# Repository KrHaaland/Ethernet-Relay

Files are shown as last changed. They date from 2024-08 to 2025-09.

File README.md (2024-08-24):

# Ethernet-Relay
Relay module using ethernet and MQTT

Put togethet with parts i had laying around.

Its based on a Atmega328p using minicore Arduino bootloader, running at 8Mhz at 3.3 volts.

Ethernet is a W5500-module brought from aliexpress, a 24LC512 for storing the web-interface, FT232 for communicating via usb and updating FW.

The mqtt topic postfix is "/relay1/set" and "/relay2/set" for turing the relays on or off, and "/relay1" or "/relay2" for getting the current status of the relays, the staus will be published according to update time set in the web-interface.

PCB is drawn in Kicad and the casing is draw using solidworks and printed on a Prusa mini+ 3D-Printer.
The print has inserts melted in place to have threads, used for fasten pcb and the back lid.

Some Instructions, the external EEPROM is written by a seperate program, since the controller is to small to contain the web page while running the primary program. When the EEPROM is written the primary program is uploaded and are using the data on the EEPROM to send the web page to a web-client request.

The FT232 is default set to 100mA, this might not be a problem if the device is powered by a charger, but beeing powered by the USB of a computer 100mA is not enough to power the ethernet or relays, this is solved using [FT_PROG](https://ftdichip.com/utilities/) to configure the FT232 to be able to draw up to 500mA.

</br><br></br><br></br><br>
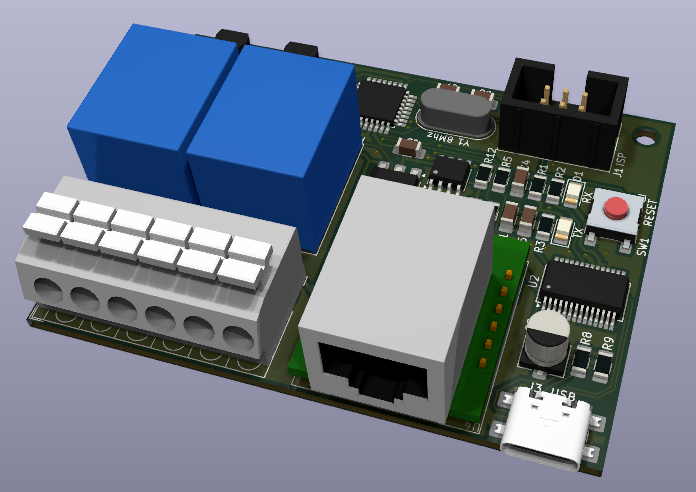
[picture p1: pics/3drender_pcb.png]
3D Render of PCB


</br><br></br><br></br><br>
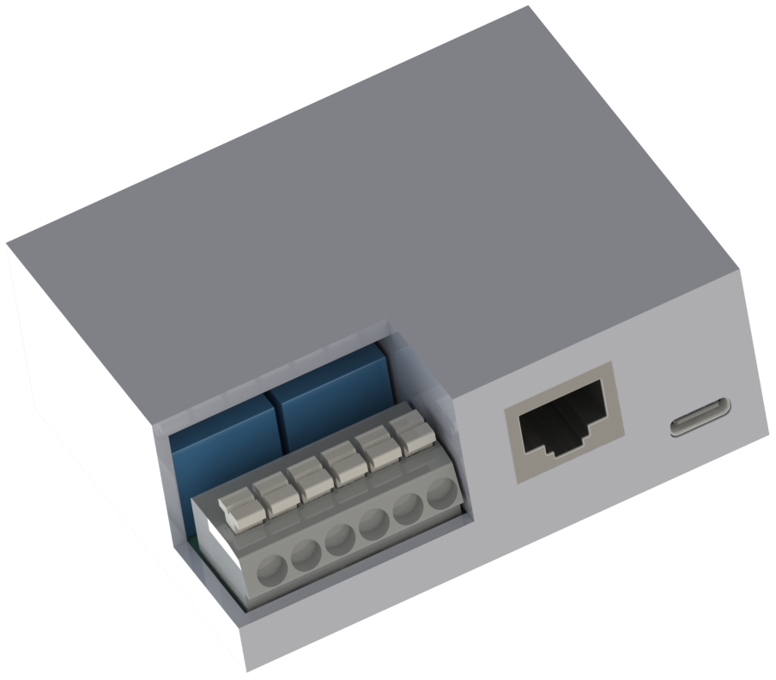
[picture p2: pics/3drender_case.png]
3D Render of case


</br><br></br><br></br><br>
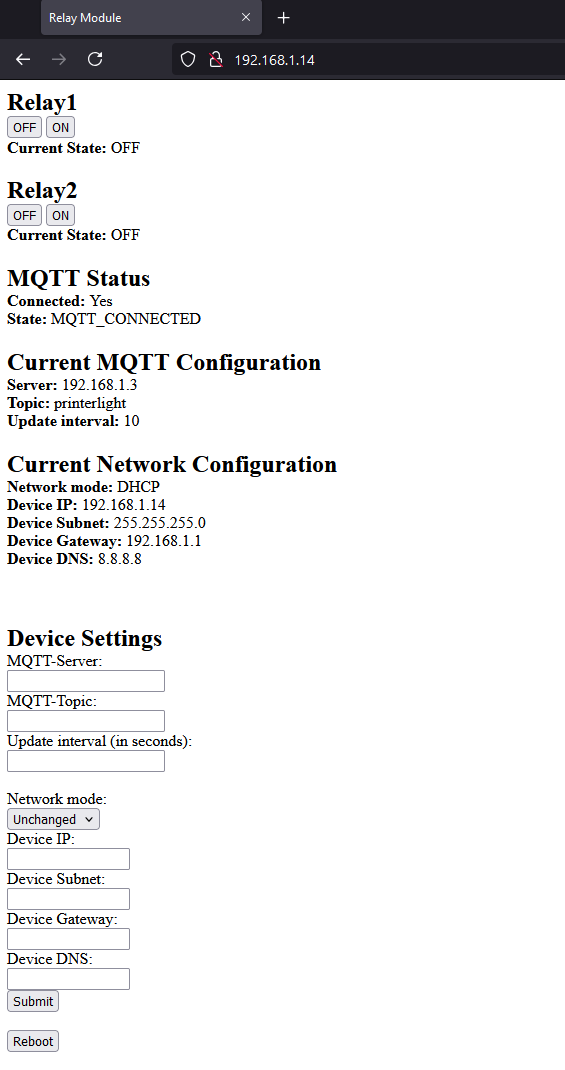
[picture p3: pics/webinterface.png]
Web Interface


</br><br></br><br></br><br>
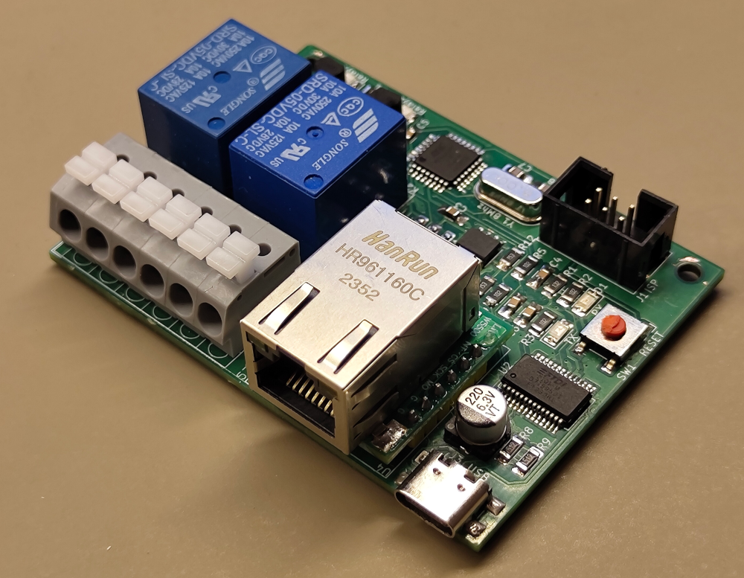
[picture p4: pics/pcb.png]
PCB


</br><br></br><br></br><br>
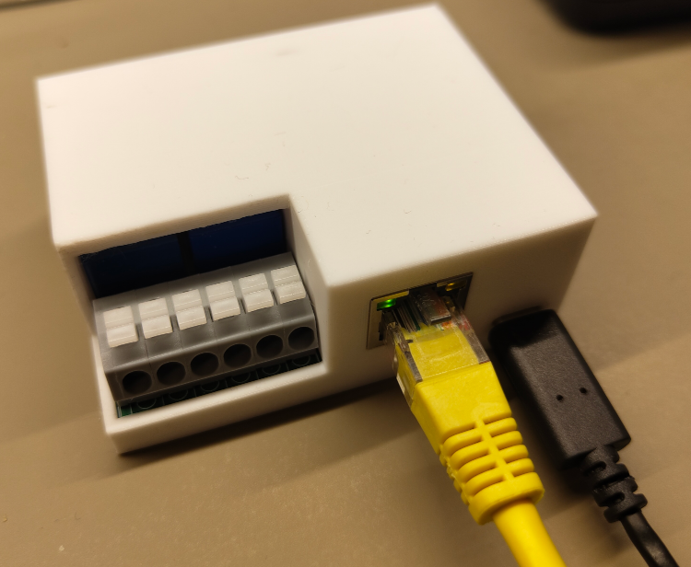
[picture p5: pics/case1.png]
Case 1


</br><br></br><br></br><br>
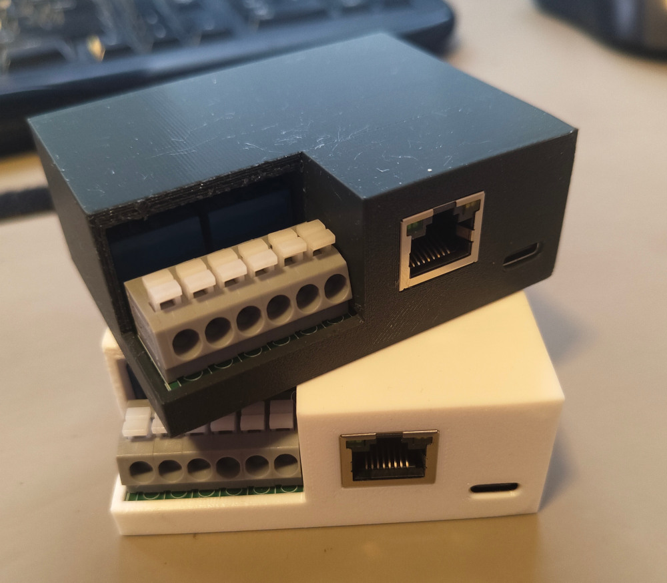
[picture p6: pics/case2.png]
Case 2


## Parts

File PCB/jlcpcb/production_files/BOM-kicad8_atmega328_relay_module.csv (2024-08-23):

Comment | Designator | Footprint | LCSC
1µF | C5 | C_1206_3216Metric_Pad1.33x1.80mm_HandSolder
16Mhz | Y1 | Crystal_HC49-4H_Vertical
SW_Omron_B3FS | SW1 | SW_SPST_Omron_B3FS-100xP
1K | R4 | R_1206_3216Metric_Pad1.30x1.75mm_HandSolder
SRD-05VDC-SL-C | K1 | Relay_SPDT_SANYOU_SRD_Series_Form_C
100µF | C2 | CP_Elec_5x5.8
1K | R1 | R_1206_3216Metric_Pad1.30x1.75mm_HandSolder
20pF | C8 | C_1206_3216Metric_Pad1.33x1.80mm_HandSolder
AVR-ISP-6 | J1 | IDC-Header_2x03_P2.54mm_Vertical
ATmega328P-A | U1 | TQFP-32_7x7mm_P0.8mm
5.1K | R9 | R_1206_3216Metric_Pad1.30x1.75mm_HandSolder
1K | R5 | R_1206_3216Metric_Pad1.30x1.75mm_HandSolder
1N4007 | D3 | D_DO-41_SOD81_P7.62mm_Horizontal
BC546 | Q2 | TO-92_Inline
1µF | C1 | C_1206_3216Metric_Pad1.33x1.80mm_HandSolder
USB_C | J3 | USB_C_Receptacle_GCT_USB4110
100nF | C4 | C_1206_3216Metric_Pad1.33x1.80mm_HandSolder
1K | R2 | R_1206_3216Metric_Pad1.30x1.75mm_HandSolder
1µF | C6 | C_1206_3216Metric_Pad1.33x1.80mm_HandSolder
AMS1117-3.3 | U3 | SOT-223-3_TabPin2
20pF | C7 | C_1206_3216Metric_Pad1.33x1.80mm_HandSolder
5.1K | R8 | R_1206_3216Metric_Pad1.30x1.75mm_HandSolder
RX-RED | D1 | LED_1206_3216Metric_Pad1.42x1.75mm_HandSolder
1K | R7 | R_1206_3216Metric_Pad1.30x1.75mm_HandSolder
1N4007 | D4 | D_DO-41_SOD81_P7.62mm_Horizontal
TX-GREEN | D2 | LED_1206_3216Metric_Pad1.42x1.75mm_HandSolder
SRD-05VDC-SL-C | K2 | Relay_SPDT_SANYOU_SRD_Series_Form_C
~ | U4 | W5500Mini
BC546 | Q1 | TO-92_Inline
1µF | C3 | C_1206_3216Metric_Pad1.33x1.80mm_HandSolder
Screw_Terminal_01x06 | J4 | TerminalBlock_WAGO_804-106_1x06_P5.00mm_45Degree
1K | R6 | R_1206_3216Metric_Pad1.30x1.75mm_HandSolder
1K | R3 | R_1206_3216Metric_Pad1.30x1.75mm_HandSolder
FT232RL | U2 | SSOP-28_5.3x10.2mm_P0.65mm
10K | R13 | R_1206_3216Metric_Pad1.30x1.75mm_HandSolder
1K | R10 | R_1206_3216Metric_Pad1.30x1.75mm_HandSolder
24LC512 | U5 | SOIC-8_3.9x4.9mm_P1.27mm
Relay1 | D5 | LED_1206_3216Metric_Pad1.42x1.75mm_HandSolder
10K | R12 | R_1206_3216Metric_Pad1.30x1.75mm_HandSolder
Relay2 | D6 | LED_1206_3216Metric_Pad1.42x1.75mm_HandSolder
1K | R11 | R_1206_3216Metric_Pad1.30x1.75mm_HandSolder

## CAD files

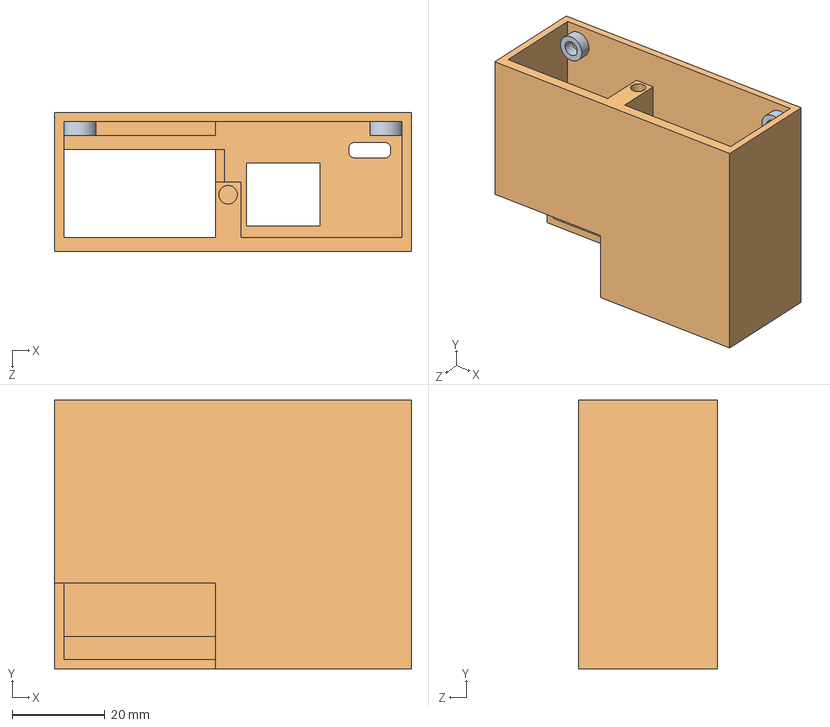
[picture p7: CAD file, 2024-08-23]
3d-files/casing.STEP
77.0 x 58.0 x 30.0 mm

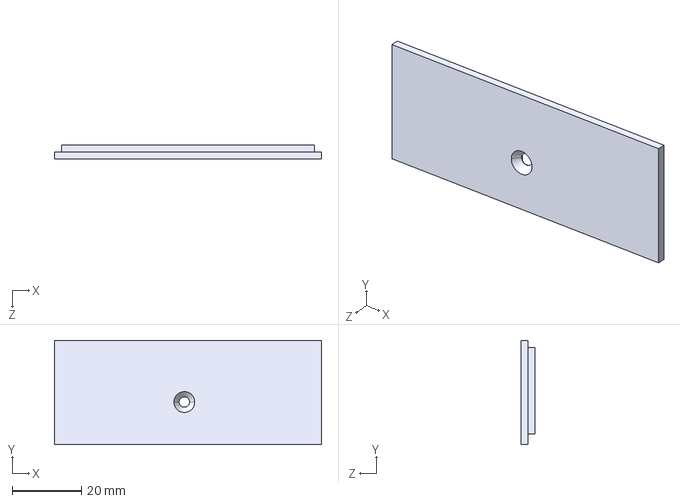
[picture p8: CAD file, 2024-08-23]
3d-files/lid.STEP
77.0 x 30.0 x 4.00 mm

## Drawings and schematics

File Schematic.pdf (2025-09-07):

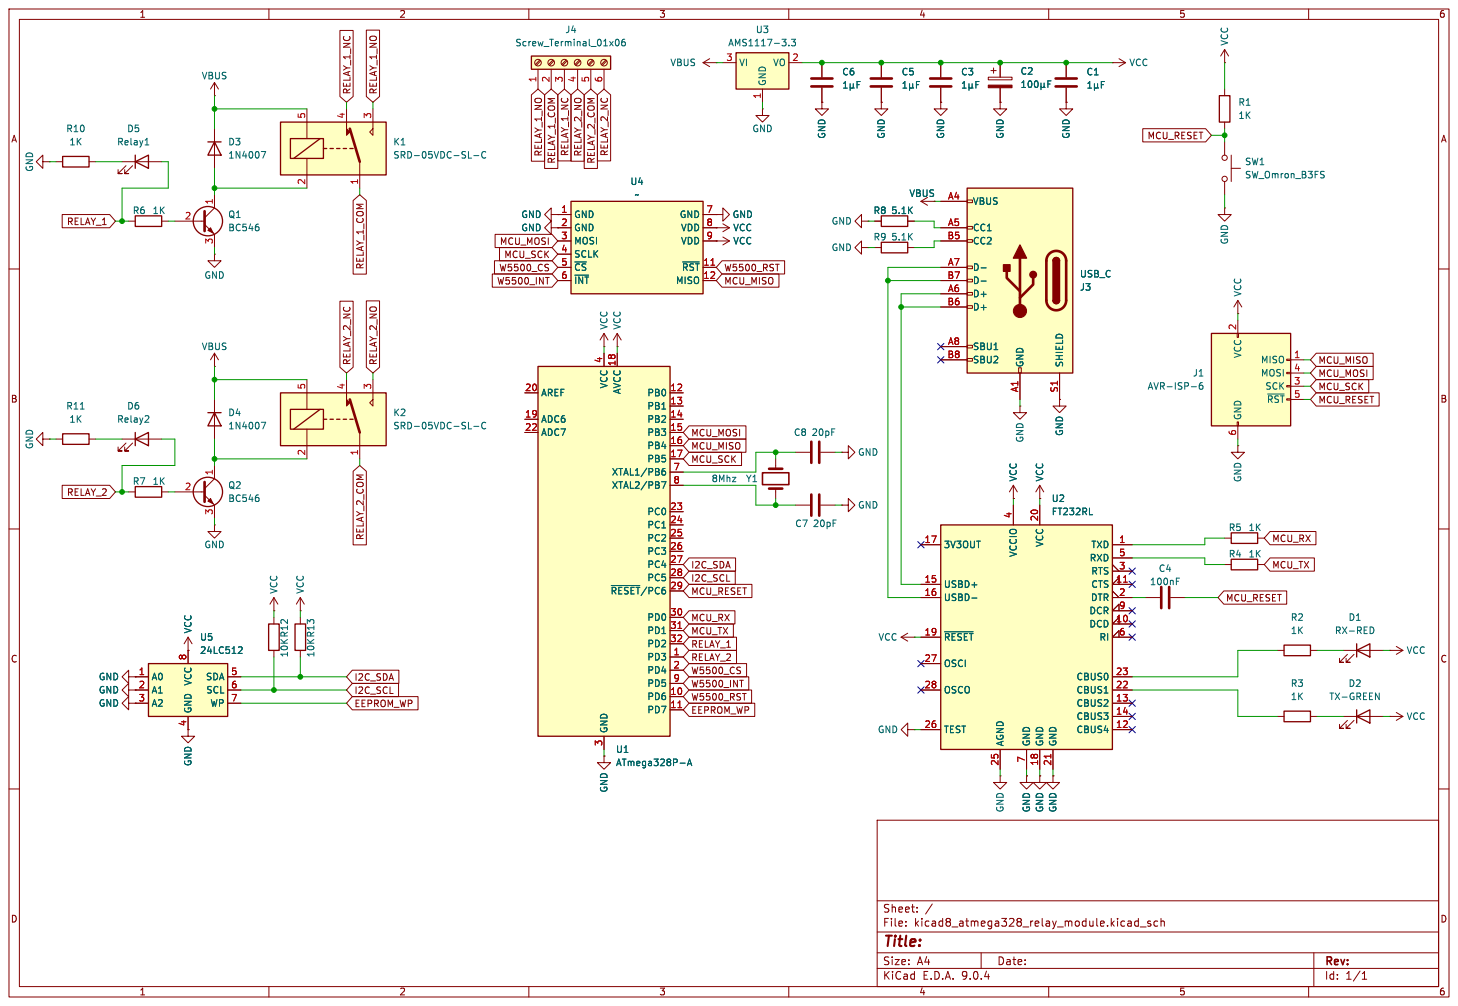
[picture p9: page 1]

7 VCC 20 GND 18 GND 21 TXD 1 RXD 5 RTS 3 CTS 11 DTR 2 DCR 9 DCD 10 RI 6 CBUS0 23 CBUS1 22 CBUS2 13 CBUS3 14 CBUS4 12 U2 FT232RL GND

3 AVCC 18 PB0 12 PB1 13 PB2 14 PB3 15 PB4 16 PB5 17 XTAL1/PB6 7 XTAL2/PB7 8 PC0 23 PC1 24 PC2 25 PC3 26 PC4 27 PC5 28 ~{RESET}/PC629 PD0 30 PD1 31 PD2 32 PD3 1 PD4 2 PD5 9 PD6 10 PD7 11 U1ATmega328P-A SHIELD S1 GND A1 VBUS A4 CC1 A5 CC2 B5 D- A7 D- B7 D+ A6 D+ B6 SBU1 A8 SBU2 B8

6 MISO 1 MOSI 4 SCK 3 ~{RST}5

3 K2SRD-05VDC-SL-C VCC GND VCC R12 10K GND VCC

7 VCC 20 GND 18 GND 21 TXD 1 RXD 5 RTS 3 CTS 11 DTR 2 DCR 9 DCD 10 RI 6 CBUS0 23 CBUS1 22 CBUS2 13 CBUS3 14 CBUS4 12 GND GND GND

4 SDA 5 SCL 6 WP 7 GND GND VCC

Id: 1/1 Title: File: kicad8_atmega328_relay_module.kicad_sch Sheet: /

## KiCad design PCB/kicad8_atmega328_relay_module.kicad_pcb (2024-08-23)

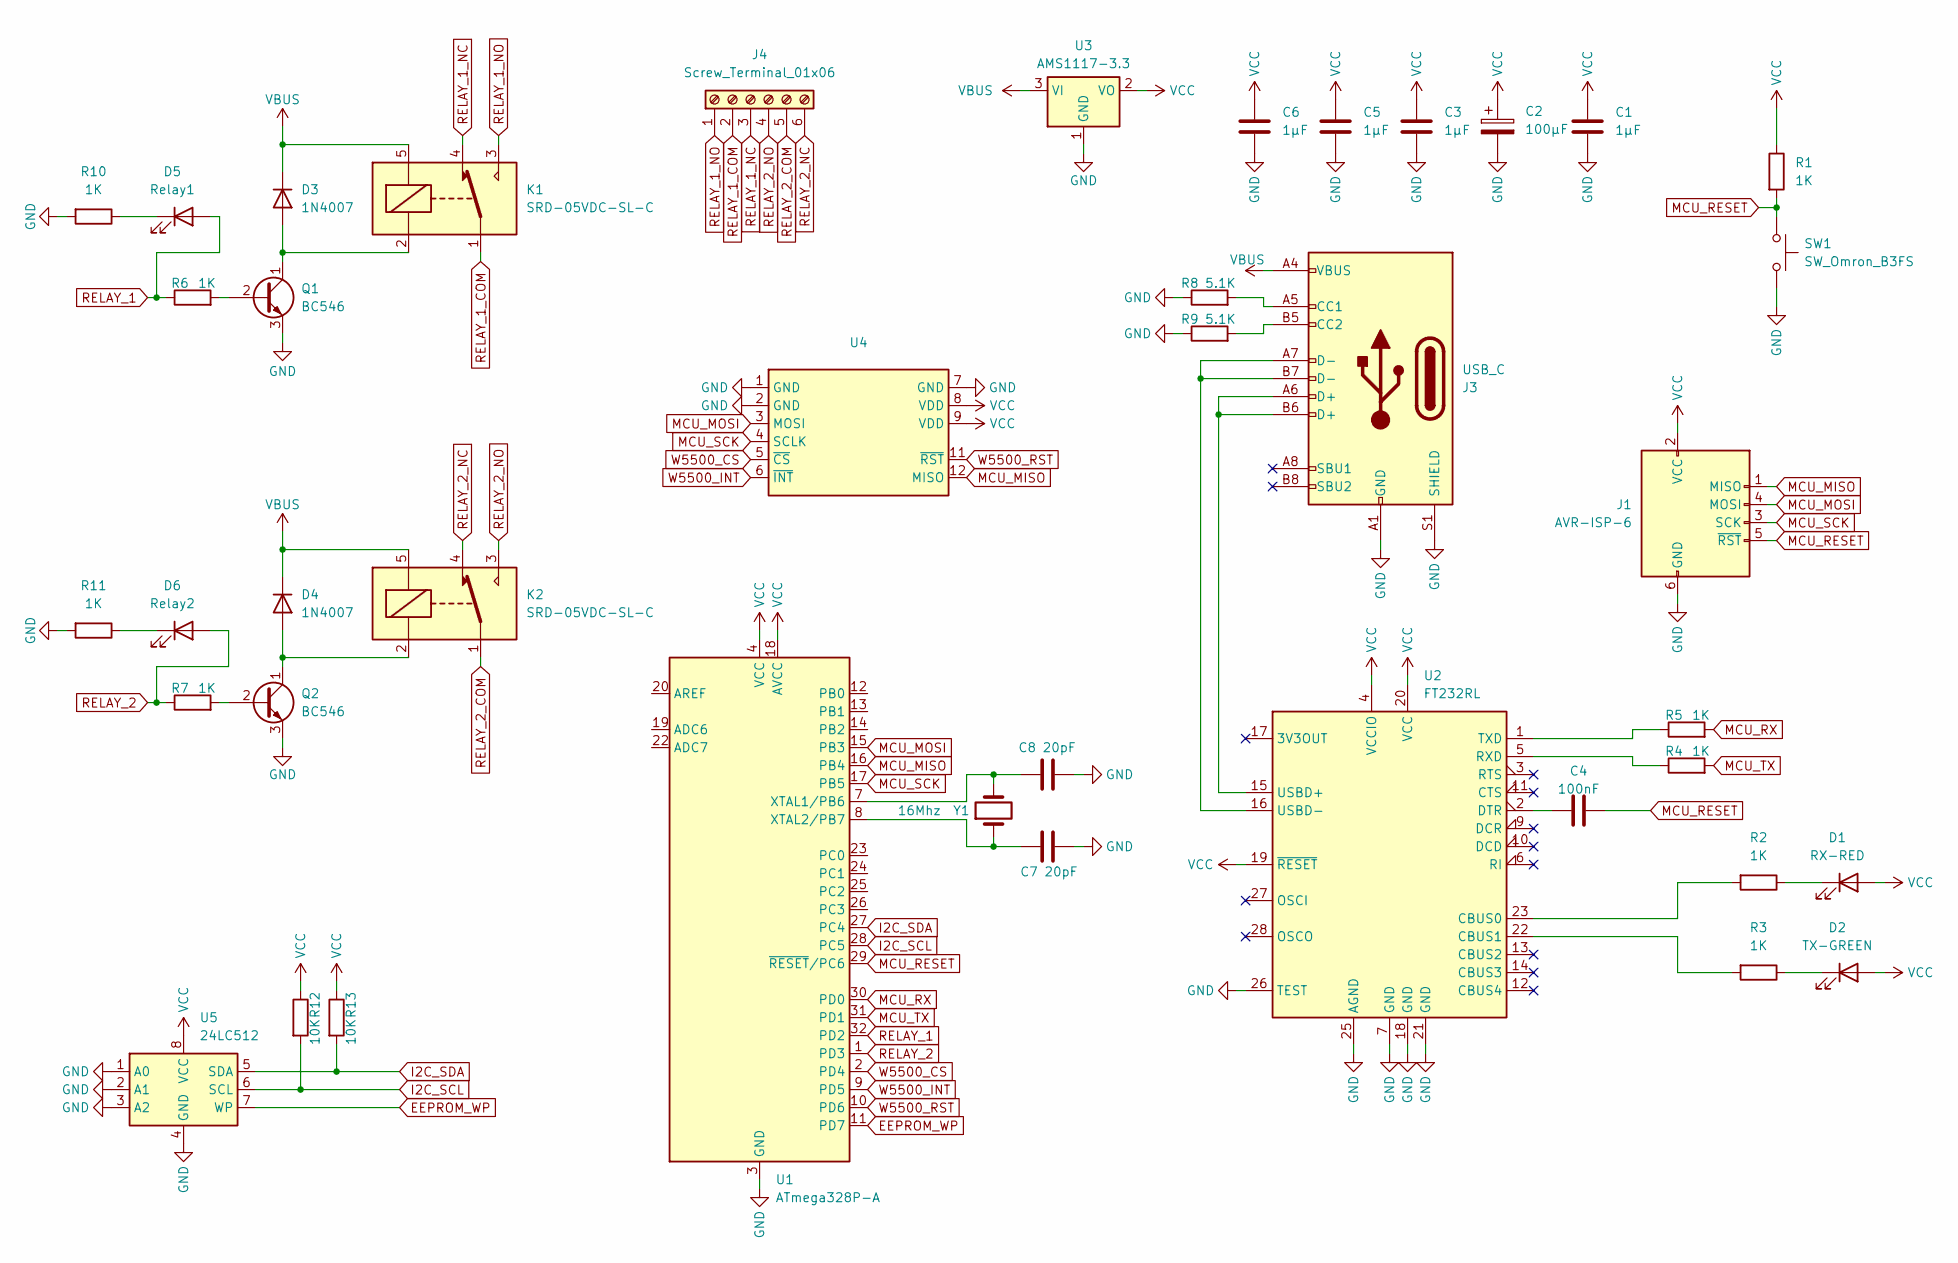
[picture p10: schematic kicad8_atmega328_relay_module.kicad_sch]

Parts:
C1, C3, C5, C6: 1µF; C_1206_3216Metric_Pad1.33x1.80mm_HandSolder
C2: 100µF; CP_Elec_5x5.8
C4: 100nF; C_1206_3216Metric_Pad1.33x1.80mm_HandSolder
C7, C8: 20pF; C_1206_3216Metric_Pad1.33x1.80mm_HandSolder
D1: RX-RED; LED_1206_3216Metric_Pad1.42x1.75mm_HandSolder
D2: TX-GREEN; LED_1206_3216Metric_Pad1.42x1.75mm_HandSolder
D3, D4: 1N4007; D_DO-41_SOD81_P7.62mm_Horizontal
D5: Relay1; LED_1206_3216Metric_Pad1.42x1.75mm_HandSolder
D6: Relay2; LED_1206_3216Metric_Pad1.42x1.75mm_HandSolder
J1: AVR-ISP-6; IDC-Header_2x03_P2.54mm_Vertical
J3: USB_C; USB_C_Receptacle_GCT_USB4110
J4: Screw_Terminal_01x06; TerminalBlock_WAGO_804-106_1x06_P5.00mm_45Degree
K1, K2: SRD-05VDC-SL-C; Relay_SPDT_SANYOU_SRD_Series_Form_C
Q1, Q2: BC546; TO-92_Inline
R1, R2, R3, R4, R5, R6, R7, R10, R11: 1K; R_1206_3216Metric_Pad1.30x1.75mm_HandSolder
R8, R9: 5.1K; R_1206_3216Metric_Pad1.30x1.75mm_HandSolder
R12, R13: 10K; R_1206_3216Metric_Pad1.30x1.75mm_HandSolder
SW1: SW_Omron_B3FS; SW_SPST_Omron_B3FS-100xP
U1: ATmega328P-A; TQFP-32_7x7mm_P0.8mm
U2: FT232RL; SSOP-28_5.3x10.2mm_P0.65mm
U3: AMS1117-3.3; SOT-223-3_TabPin2
U4: W5500Mini
U5: 24LC512; SOIC-8_3.9x4.9mm_P1.27mm
Y1: 16Mhz; Crystal_HC49-4H_Vertical

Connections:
EEPROM_WP: U1.11 (PD7), U5.7 (WP)
GND: C1.2, C2.2, C3.2, C5.2, C6.2, C7.2, C8.2, J1.6 (GND), J3.A1 (GND), J3.A12 (GND), J3.B1 (GND), J3.B12 (GND), J3.S1 (SHIELD), Q1.3 (E), Q2.3 (E), R8.1, R9.1, R10.2, R11.2, SW1.2, U1.3 (GND), U1.5 (GND), U1.21 (GND), U2.7 (GND), U2.18 (GND), U2.21 (GND), U2.25 (AGND), U2.26 (TEST), U3.1 (GND), U4.1 (GND), U4.2 (GND), U4.7 (GND), U5.1 (A0), U5.2 (A1), U5.3 (A2), U5.4 (GND)
I2C_SCL: R12.2, U1.28 (PC5), U5.6 (SCL)
I2C_SDA: R13.2, U1.27 (PC4), U5.5 (SDA)
MCU_MISO: J1.1 (MISO), U1.16 (PB4), U4.12 (MISO)
MCU_MOSI: J1.4 (MOSI), U1.15 (PB3), U4.3 (MOSI)
MCU_RESET: C4.1, J1.5 (~RST), R1.2, SW1.1, U1.29 (~RESET/PC6)
MCU_RX: R5.2, U1.30 (PD0)
MCU_SCK: J1.3 (SCK), U1.17 (PB5), U4.4 (SCLK)
MCU_TX: R4.2, U1.31 (PD1)
unnamed: D1.1 (K), R2.1
unnamed: D2.1 (K), R3.1
unnamed: D3.2 (A), K1.2, Q1.1 (C)
unnamed: D4.2 (A), K2.2, Q2.1 (C)
unnamed: D5.1 (K), R10.1
unnamed: D6.1 (K), R11.1
unnamed: J3.A5 (CC1), R8.2
unnamed: J3.B5 (CC2), R9.2
unnamed: Q1.2 (B), R6.2
unnamed: Q2.2 (B), R7.2
unnamed: C8.1, U1.7 (XTAL1/PB6), Y1.2
unnamed: C7.1, U1.8 (XTAL2/PB7), Y1.1
unnamed: R2.2, U2.23 (CBUS0)
unnamed: R3.2, U2.22 (CBUS1)
unnamed: C4.2, U2.2 (DTR)
unnamed: R4.1, U2.5 (RXD)
unnamed: R5.1, U2.1 (TXD)
RELAY_1: D5.2 (A), R6.1, U1.32 (PD2)
RELAY_1_COM: J4.2, K1.1
RELAY_1_NC: J4.3, K1.4
RELAY_1_NO: J4.1, K1.3
RELAY_2: D6.2 (A), R7.1, U1.1 (PD3)
RELAY_2_COM: J4.5, K2.1
RELAY_2_NC: J4.6, K2.4
RELAY_2_NO: J4.4, K2.3
USB_D+: J3.A6 (D+), J3.B6 (D+), U2.15 (USBD+)
USB_D-: J3.A7 (D-), J3.B7 (D-), U2.16 (USBD-)
VBUS: D3.1 (K), D4.1 (K), J3.A4 (VBUS), J3.A9 (VBUS), J3.B4 (VBUS), J3.B9 (VBUS), K1.5, K2.5, U3.3 (VI)
VCC: C1.1, C2.1, C3.1, C5.1, C6.1, D1.2 (A), D2.2 (A), J1.2 (VCC), R1.1, R12.1, R13.1, U1.4 (VCC), U1.6 (VCC), U1.18 (AVCC), U2.4 (VCCIO), U2.19 (~RESET), U2.20 (VCC), U3.2 (VO), U4.8 (VDD), U4.9 (VDD), U5.8 (VCC)
W5500_CS: U1.2 (PD4), U4.5 (~CS)
W5500_INT: U1.9 (PD5), U4.6 (~INT)
W5500_RST: U1.10 (PD6), U4.11 (~RST)

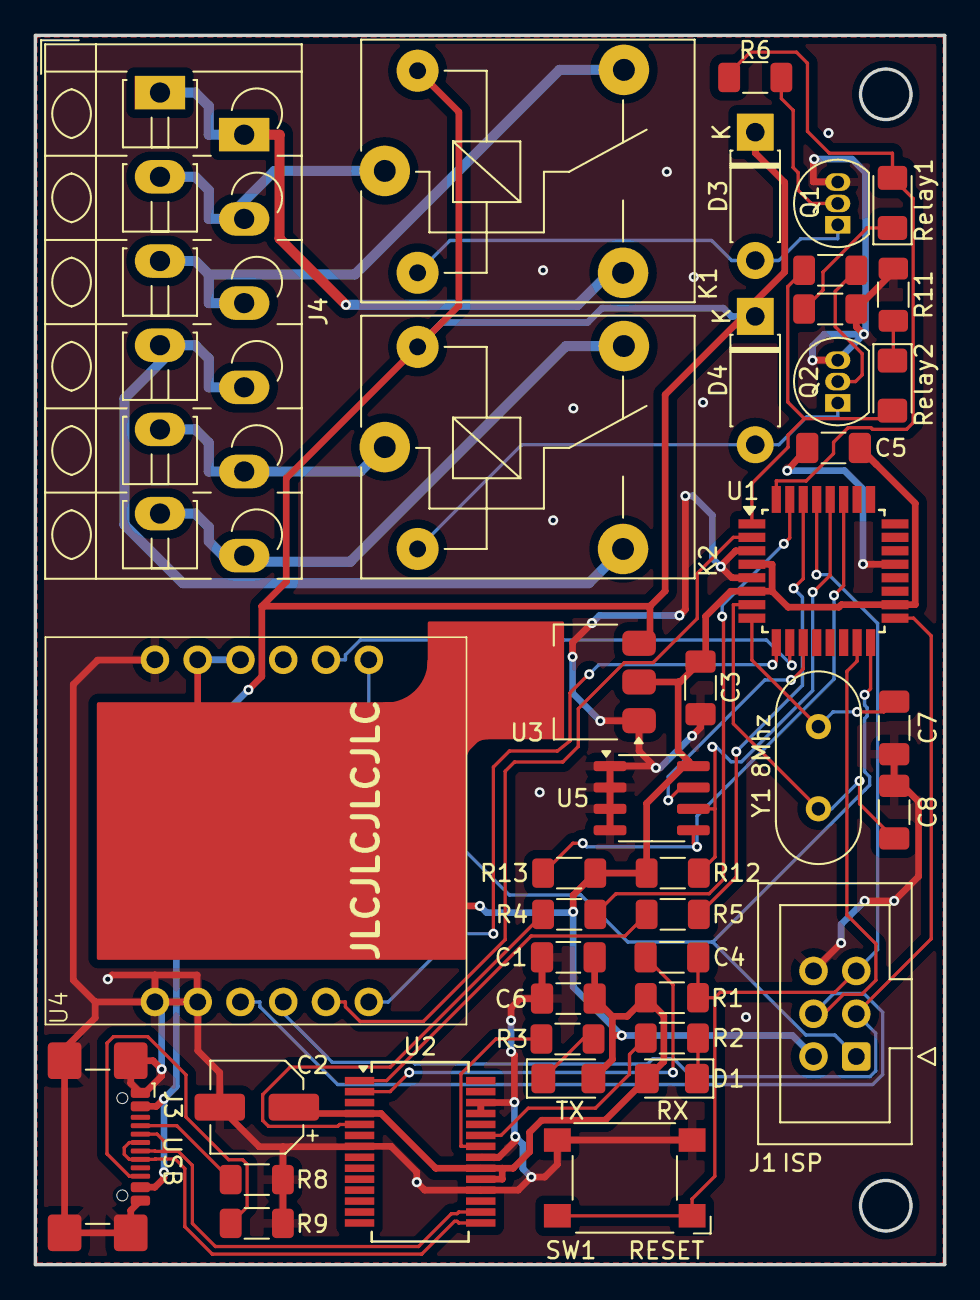
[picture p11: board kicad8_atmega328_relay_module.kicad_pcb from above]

Board: 2 copper layers, 54.0 x 73.0 mm, 41 parts (0 on the bottom side), 42 nets.

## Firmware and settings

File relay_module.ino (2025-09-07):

/**************************************
SOME NOTES

FT232:
Use FT_PROG to set bus power to 500mA,
Otherwise it wont give enough power to
supply ethernet module and relays!



/*************************************/

#include <SPI.h>
#include <Wire.h>
#include <PubSubClient.h>
#include <EEPROM.h>
#include <Ethernet.h>
#include <avr/wdt.h>
#include <avr/io.h>

// MAC address for your Ethernet shield
// BE SURE TO ALSO CHANGE MQTT CLIENT ID and serial output !!
//byte mac[] = { 0x02, 0x79, 0xFB, 0x22, 0x8C, 0x10 };  // First produced module
byte mac[] = { 0x0E, 0x97, 0xBF, 0xCF, 0x2F, 0x95 };  // Second produced module
#define W5500_CS   PIN_PD4
#define W5500_RST  PIN_PD6

//relays
#define RELAY1PIN PIN_PD2
#define RELAY2PIN PIN_PD3

// Initialize the Ethernet server
EthernetServer server(80);

// MQTT Client
EthernetClient ethClient;
PubSubClient mqttClient(ethClient);

// i2c-frequency
const uint16_t i2cclockfrequency = 400000;
#define EEPROM_I2C_ADDRESS 0x50  // The I2C address for the 24C512 EEPROM

// Global variables
unsigned long previousMillismeasure = 0;
int lastStaterelay1 = LOW;    // Variable to store the last state of the input
int lastStaterelay2 = LOW;    // Variable to store the last state of the input

void(* reboot) (void) = 0; //declare reset function at address 0

void restartMicrocontroller() {
  wdt_enable(WDTO_1S);  // Enable Watchdog Timer with a timeout of 15ms
}

// Function to connect to MQTT server
void connectToMqtt() {
  mqttClient.loop();
  char mqttServer[64];
  retrieveFromEEPROM2(32, mqttServer, sizeof(mqttServer));
  Serial.print(F("mqtt: "));
  Serial.println(mqttServer);
  mqttClient.setServer(mqttServer, 1883);

  while (!mqttClient.connected()) {
    Serial.println(F("Connecting to MQTT..."));
    if (mqttClient.connect("0E97BFCF2F95")) {
      Serial.println(F("Connected to MQTT"));

      // Subscribe to topics
      char mqttTopic[64];
      retrieveFromEEPROM2(96, mqttTopic, sizeof(mqttTopic));
      char topic1[70];
      char topic2[70];
      strcpy(topic1, mqttTopic);
      strcat(topic1, "/relay1/set");
      strcpy(topic2, mqttTopic);
      strcat(topic2, "/relay2/set");
      mqttClient.subscribe(topic1);
      mqttClient.subscribe(topic2);

    } 
    else {
      Serial.print(F("Failed, rc="));
      Serial.println(mqttClient.state());
      delay(5000);
    }
  }
}

// MQTT message callback function
void callback(char* topic, byte* payload, unsigned int length) {
  payload[length] = '\0'; // Null-terminate the payload
  String message = String((char*)payload);

  Serial.print(F("Message arrived ["));
  Serial.print(topic);
  Serial.print(F("] "));
  Serial.println(message);

  // Check the topic and payload to control relays
  if (strstr(topic, "/relay1/set")) {
    if (message == "ON" || message == "1") {
      digitalWrite(RELAY1PIN, HIGH);
      Serial.println(F("Relay 1 turned ON"));
    } else if (message == "OFF" || message == "0") {
      digitalWrite(RELAY1PIN, LOW);
      Serial.println(F("Relay 1 turned OFF"));
    }
  } else if (strstr(topic, "/relay2/set")) {
    if (message == "ON" || message == "1") {
      digitalWrite(RELAY2PIN, HIGH);
      Serial.println(F("Relay 2 turned ON"));
    } else if (message == "OFF" || message == "0") {
      digitalWrite(RELAY2PIN, LOW);
      Serial.println(F("Relay 2 turned OFF"));
    }
  }
}

// Function to publish to a specific subtopic
void publishToSubtopic(char* baseTopic, const char* subtopic, const char* message) {
  char fullTopic[75]; // Ensure this buffer is large enough
  strcpy(fullTopic, baseTopic);
  strcat(fullTopic, subtopic); // Directly concatenate the subtopic
  mqttClient.publish(fullTopic, message);
}

void processClientRequest(EthernetClient& client) {
  //Serial.println(freeMemory());
String httpReq = "";
bool gotGet = false;
bool gotHost = false;
String currentLine = "";

while (client.connected()) {
    if (client.available()) {
        char c = client.read();
        currentLine += c;

        // Look for lines that starts with "GET" and "Host" 
        // and keep only them, this in order to save ram

        // Check for the end of the line
        if (c == '\n') {
            // Check if the line contains "GET"
            if (currentLine.startsWith(F("GET"))) {
                gotGet = true;
                httpReq += currentLine;
            }

            // Check if the line contains "Host"
            if (currentLine.startsWith(F("Host"))) {
                gotHost = true;
                httpReq += currentLine;
            }

            // Clear the current line
            currentLine = "";
        String hostValue;
        if (gotGet && gotHost) {
          Serial.println(httpReq);
          // Check for "Host: " header
          // This is used to know if it should redirect back to IP or mDNS-name
          int pos1 = httpReq.indexOf(F("Host: "));
          if (pos1 != -1) {
            int endOfLineIndex = httpReq.indexOf('\n', pos1);
            hostValue = httpReq.substring(pos1 + 6, endOfLineIndex); // +6 to skip past "Host: "
          }
          // Check for "GET: " header
          int pos = httpReq.indexOf(F("GET /?in1="));
          if (pos != -1) {
            pos += 10; // Skip past "GET /?input1="
            // Extract input1
            int nextAmp = httpReq.indexOf('&', pos);
            String input1 = httpReq.substring(pos, nextAmp);

            // Extract input2
            pos = httpReq.indexOf(F("in2="), nextAmp) + 4;
            nextAmp = httpReq.indexOf('&', pos);
            String input2 = httpReq.substring(pos, nextAmp);

            // Extract input3
            pos = httpReq.indexOf(F("in3="), nextAmp) + 4;
            int endPos = httpReq.indexOf('&', pos);
            String input3 = httpReq.substring(pos, endPos);

            // Extract DHCP-selection
            pos = httpReq.indexOf(F("net="), nextAmp) + 4;
            endPos = httpReq.indexOf('&', pos);
            String dhcpselect = httpReq.substring(pos, endPos);

            // Extract input4
            pos = httpReq.indexOf(F("in4="), nextAmp) + 4;
            endPos = httpReq.indexOf('&', pos);
            String input4 = httpReq.substring(pos, endPos);

            // Extract input5
            pos = httpReq.indexOf(F("in5="), nextAmp) + 4;
            endPos = httpReq.indexOf('&', pos);
            String input5 = httpReq.substring(pos, endPos);

            // Extract input6
            pos = httpReq.indexOf(F("in6="), nextAmp) + 4;
            endPos = httpReq.indexOf('&', pos);
            String input6 = httpReq.substring(pos, endPos);

            // Extract input7
            pos = httpReq.indexOf(F("in7="), nextAmp) + 4;
            endPos = httpReq.indexOf(' HTTP/1.1', pos) - 6;
            String input7 = httpReq.substring(pos, endPos);

            // Redirect browser back after pressing "submit"-button
            Serial.print(F("redirecting back to "));
            Serial.println(hostValue);
            client.println(F("HTTP/1.1 302 Found"));
            client.print(F("Location: http://"));
            client.print(hostValue);
            client.println(F("/"));
            client.println(F("Connection: close"));
            client.println();
            // Store in EEPROM, unless input is empty
            // Store MQTT-Server
            if (input1 != NULL){
              input1.replace("%2F", "/");
              storeInEEPROM(32, input1.substring(0, 63)); // Trim the string to the first 32 characters);
              // disconnect MQTT-server in case server-config is updated
              mqttClient.disconnect();
            }
            // Store MQTT-Topic
            if (input2 != NULL){
              input2.replace("%2F", "/");
              storeInEEPROM(96, input2.substring(0, 63)); // Trim the string to the first 32 characters);
              Serial.println(input2.substring(0, 63)); // Trim the string to the first 32 characters););
            }

            // Store update interval)
            if (input3 != NULL){
              unsigned int intinterval = input3.toInt();
              // Break the integer into two bytes
              byte lowByte = intinterval & 0xFF;
              byte highByte = (intinterval >> 8) & 0xFF;
              EEPROM.write(17, lowByte);
              EEPROM.write(18, highByte);
              Serial.println(String(intinterval));
            }          
          
            // Store DHCP-mode
            if (dhcpselect != NULL){
              if ((dhcpselect == "Static") && (EEPROM.read(0) != 1)) {
              EEPROM.write(0, 1);
              Serial.println(F("1 Was stored to EEPROM (Static)"));
              // Reboot to apply new settings
              reboot();
              }
              if ((dhcpselect == F("DHCP")) && (EEPROM.read(0) != 0)) {
              EEPROM.write(0, 0);
              Serial.println(F("0 Was stored to EEPROM (DHCP)"));
              // Reboot to apply new settings
              reboot();
              }              
            } 
            // Store Device-IP
            if (input4 != NULL){
              int ip1, ip2, ip3, ip4;
              char ipCharArray[16];
              input4.toCharArray(ipCharArray, sizeof(ipCharArray));
              sscanf(ipCharArray, "%d.%d.%d.%d", &ip1, &ip2, &ip3, &ip4);
              EEPROM.write(1, ip1);
              EEPROM.write(2, ip2);
              EEPROM.write(3, ip3);
              EEPROM.write(4, ip4);
            } 

            // Store Device-subnet
            if (input5 != NULL){
              int ip5, ip6, ip7, ip8;
              char subCharArray[16];
              input5.toCharArray(subCharArray, sizeof(subCharArray));
              sscanf(subCharArray, "%d.%d.%d.%d", &ip5, &ip6, &ip7, &ip8);
              EEPROM.write(5, ip5);
              Serial.print(ip5);
              Serial.print(".");
              EEPROM.write(6, ip6);
              Serial.print(ip6);
              Serial.print(".");              
              EEPROM.write(7, ip7);
              Serial.print(ip7);
              Serial.print(".");
              EEPROM.write(8, ip8);
              Serial.println(ip8);              
            } 
            // Store Device-gateway
            if (input6 != NULL){
              int ip9, ip10, ip11, ip12;
              char gwCharArray[16];
              input6.toCharArray(gwCharArray, sizeof(gwCharArray));
              sscanf(gwCharArray, "%d.%d.%d.%d", &ip9, &ip10, &ip11, &ip12);
              EEPROM.write(9, ip9);
              EEPROM.write(10, ip10);
              EEPROM.write(11, ip11);
              EEPROM.write(12, ip12);
            } 
            // Store Device-dns
            if (input7 != NULL){
              int ip13, ip14, ip15, ip16;
              char dnsCharArray[16];
              input7.toCharArray(dnsCharArray, sizeof(dnsCharArray));
              sscanf(dnsCharArray, "%d.%d.%d.%d", &ip13, &ip14, &ip15, &ip16);
              EEPROM.write(13, ip13);
              EEPROM.write(14, ip14);
              EEPROM.write(15, ip15);
              EEPROM.write(16, ip16);
            } 

            // Debug print
            Serial.print(F("Input 1: "));
            Serial.println(input1);
            Serial.print(F("Input 2: "));
            Serial.println(input2);
            Serial.print(F("Input 3: "));
            Serial.println(input3);
            Serial.print(F("Input 4: "));
            Serial.println(input4);
            Serial.print(F("Input 5: "));
            Serial.println(input5);
            Serial.print(F("Input 6: "));
            Serial.println(input6);
            Serial.print(F("Input 7: "));
            Serial.println(input7);
            Serial.print(F("netmode: "));
            Serial.println(dhcpselect);       
            Serial.println(freeMemory());
          }

          // check for relay change
          if (httpReq.startsWith(F("GET /?onRelay1 "))) {
            digitalWrite(RELAY1PIN, HIGH); // sets the relay1 on
          }  
          if (httpReq.startsWith(F("GET /?offRelay1 "))) {
            digitalWrite(RELAY1PIN, LOW); // sets the relay1 off
          }  
          if (httpReq.startsWith(F("GET /?onRelay2 "))) {
            digitalWrite(RELAY2PIN, HIGH); // sets the relay2 on
          }  
          if (httpReq.startsWith(F("GET /?offRelay2 "))) {
            digitalWrite(RELAY2PIN, LOW); // sets the relay2 off
          }  

          // check if reboot-button is pressed
          if (httpReq.startsWith(F("GET /?reboot "))) {
            restartMicrocontroller();
          }  

          // send requesed data to webpage
          if (httpReq.startsWith(F("GET /getData "))) {      
            client.println(F("HTTP/1.1 200 OK"));
            client.println(F("Content-Type: application/json"));
            client.println(F("Connection: close"));
            client.println();

            // Construct JSON response
            client.print(F("{\"relay1status\":\""));
            if (digitalRead(RELAY1PIN) == LOW) {
              client.print(F("OFF"));
            }
            if (digitalRead(RELAY1PIN) == HIGH) {
              client.print(F("ON"));
            }

            client.print(F("\", \"relay2status\":\""));
            if (digitalRead(RELAY2PIN) == LOW) {
              client.print(F("OFF"));
            }
            if (digitalRead(RELAY2PIN) == HIGH) {
              client.print(F("ON"));
            }

            client.print(F("\", \"mqtt_connected\":\""));
            if (!mqttClient.connected()) {
              client.print(F("No"));
            }
            if (mqttClient.connected()) {
              client.print(F("Yes"));
            }

            client.print(F("\", \"mqtt_status\":\""));
            int8_t mqttstate = mqttClient.state();
            if (mqttstate == -4) { client.print(F("MQTT_CONNECTION_TIMEOUT")); }
            if (mqttstate == -3) { client.print(F("MQTT_CONNECTION_LOST")); }
            if (mqttstate == -2) { client.print(F("MQTT_CONNECT_FAILED")); }
            if (mqttstate == -1) { client.print(F("MQTT_DISCONNECTED")); }
            if (mqttstate == 0) { client.print(F("MQTT_CONNECTED")); }
            if (mqttstate == 1) { client.print(F("MQTT_CONNECT_BAD_PROTOCOL")); }
            if (mqttstate == 2) { client.print(F("MQTT_CONNECT_BAD_CLIENT_ID")); }
            if (mqttstate == 3) { client.print(F("MQTT_CONNECT_UNAVAILABLE")); }
            if (mqttstate == 4) { client.print(F("MQTT_CONNECT_BAD_CREDENTIALS")); }
            if (mqttstate == 5) { client.print(F("MQTT_CONNECT_UNAUTHORIZED")); }

            client.print(F("\", \"mqtt_current_ip\":\""));
            client.print(retrieveFromEEPROM1(32));

            client.print(F("\", \"mqtt_current_topic\":\""));
            client.print(retrieveFromEEPROM1(96));

            client.print(F("\", \"mqtt_current_update_interval\":\""));
            byte lowByte = EEPROM.read(17);
            byte highByte = EEPROM.read(18);
            unsigned int interval = (highByte << 8) | lowByte;
            client.print(String(interval));

            client.print(F("\", \"device_current_networkmode\":\""));
            if (EEPROM.read(0) == 0) {
              client.print(F("DHCP"));
            }
            if (EEPROM.read(0) == 1) {
              client.print(F("Static"));
            }

            client.print(F("\", \"device_current_ip\":\""));
            client.print(Ethernet.localIP());

            client.print(F("\", \"device_current_subnet\":\""));
            client.print(Ethernet.subnetMask());

            client.print(F("\", \"device_current_gw\":\""));
            client.print(Ethernet.gatewayIP());

            client.print(F("\", \"device_current_dns\":\""));
            client.print(Ethernet.dnsServerIP());

            client.println(F("\"}"));      
          }


/*

          // Send webpage
          // ethernet library changes SPI frequency every time its used,
          // usualy way higher then what EEPROM is capaple of, therefore
          // it is necessary to change SPI frequency before reading from EEPROM
          // this might not be a problem with other EEPROMs, the one used for
          // prototyping is a 25LC640 (max 3Mhz)
          // other like the 25LC512 can go as high as 20Mhz, while the ethernet
          // is set for 14Mhz
          if (httpReq.startsWith("GET / ")) {
            for (int i = 0; i < 7730; i++) {
              SPI.beginTransaction(SPISettings(ExtEEPROMSPIclockfrequency, MSBFIRST, SPI_MODE0));
              digitalWrite(EEPROM_CS_PIN, LOW);
              SPI.transfer(3); // (READ);
              SPI.transfer16(i); // Address
              char data = SPI.transfer(0); // (data);
              digitalWrite(EEPROM_CS_PIN, HIGH);
              client.print(data);
            }
          }
*/
/*
          if (httpReq.startsWith("GET / ")) {        
            char buffer[16];
            int len = strlen_P(webpage);
            for (int i = 0; i < len; i += sizeof(buffer) - 1) {
              strncpy_P(buffer, webpage + i, sizeof(buffer) - 1);
              buffer[sizeof(buffer) - 1] = '\0';
              client.print(buffer);
            }
          }
*/

          if (httpReq.startsWith(F("GET / "))) {        
            const int chunkSize = 32;  // Number of bytes to read at a time, safe for ATmega328's TWI buffer
            char buffer[chunkSize + 1]; // Buffer to store read bytes (+1 for null terminator)

            for (int i = 0; i < 7864; i += chunkSize) {
              int address = i;
              int bytesToRead = min(chunkSize, 7864 - address); // Calculate how many bytes to read in this iteration

              Wire.beginTransmission(EEPROM_I2C_ADDRESS);
              Wire.write((address >> 8) & 0xFF);  // MSB of the address
              Wire.write(address & 0xFF);         // LSB of the address
              Wire.endTransmission();

              Wire.requestFrom(EEPROM_I2C_ADDRESS, bytesToRead); // Request the specified number of bytes
              for (int j = 0; j < bytesToRead; j++) {
                if (Wire.available()) {
                  buffer[j] = Wire.read(); // Read each byte into the buffer
                } else {
                  buffer[j] = 0xFF; // Default value if no data is available
                }
              }
              buffer[bytesToRead] = '\0'; // Null terminate the buffer for safe printing
              client.print(buffer); // Print the buffer to the Serial monitor
              //delay(1); // Small delay to ensure reliability
            }
          }



/*
          // give an update on RAM when page is reloaded
          Serial.print(F("Free memory: "));
          Serial.print(freeMemory());
          Serial.println(F(" bytes"));
          */

          break; // Exit the while loop
        }
      }
    }
  }
}

void storeInEEPROM(int address, const String &data) {
  int i;
  for (i = 0; i < data.length(); i++) {
    EEPROM.write(address + i, data[i]);
  }
  // Write a null character at the end to mark the end of the string
  EEPROM.write(address + i, '\0');
}
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
void loop() {

  // check if relay is toggled
  int currentStaterelay1 = digitalRead(RELAY1PIN); // Read the current state of the input pin
  int currentStaterelay2 = digitalRead(RELAY2PIN); // Read the current state of the input pin
  char mqttTopic[64];
  retrieveFromEEPROM2(96, mqttTopic, sizeof(mqttTopic));
  if (lastStaterelay1 == HIGH && currentStaterelay1 == LOW) {
    publishToSubtopic(mqttTopic, "/relay1", "OFF");
    Serial.println(F("relay1: 0"));
  }
  if (lastStaterelay1 == LOW && currentStaterelay1 == HIGH) {
    publishToSubtopic(mqttTopic, "/relay1", "ON");
    Serial.println(F("relay1: 1"));
  }  
  if (lastStaterelay2 == HIGH && currentStaterelay2 == LOW) {
    publishToSubtopic(mqttTopic, "/relay2", "OFF");
    Serial.println(F("relay2: 0"));
  }
  if (lastStaterelay2 == LOW && currentStaterelay2 == HIGH) {
    publishToSubtopic(mqttTopic, "/relay2", "ON");
    Serial.println(F("relay2: 1"));
  }  
  lastStaterelay1 = currentStaterelay1;
  lastStaterelay2 = currentStaterelay2;


  unsigned long currentMillismeasure = millis();
  byte lowByte = EEPROM.read(17);
  byte highByte = EEPROM.read(18);
  unsigned int interval = (highByte << 8) | lowByte;
  if (interval == 0) {
    interval = 1;
  }
  // MQTT publishing
  if (!mqttClient.connected()) {
    connectToMqtt();
  }
  mqttClient.loop();
  if (currentMillismeasure - previousMillismeasure >= (interval * 1000)) {
    previousMillismeasure = currentMillismeasure;


    // Publish data
    if (digitalRead(RELAY1PIN) == LOW){
      char mqttTopic[64];
      retrieveFromEEPROM2(96, mqttTopic, sizeof(mqttTopic));
      publishToSubtopic(mqttTopic, "/relay1", "OFF");
    }
    if (digitalRead(RELAY1PIN) == HIGH){
      char mqttTopic[64];
      retrieveFromEEPROM2(96, mqttTopic, sizeof(mqttTopic));      
      publishToSubtopic(mqttTopic, "/relay1", "ON");
    }
    if (digitalRead(RELAY2PIN) == LOW){
      char mqttTopic[64];
      retrieveFromEEPROM2(96, mqttTopic, sizeof(mqttTopic));      
      publishToSubtopic(mqttTopic, "/relay2", "OFF");
    }
    if (digitalRead(RELAY2PIN) == HIGH){
      char mqttTopic[64];
      retrieveFromEEPROM2(96, mqttTopic, sizeof(mqttTopic));      
      publishToSubtopic(mqttTopic, "/relay2", "ON");
    }  


/*
    // give an update on RAM when page is reloaded
    Serial.print(F("Free memory: "));
    Serial.print(freeMemory());
    Serial.println(F(" bytes"));
*/
  }


  // Listen for incoming clients
  EthernetClient client = server.available();
  if (client) {
    Serial.println(client);
    processClientRequest(client);
    delay(1);
    client.stop();
  }
}
